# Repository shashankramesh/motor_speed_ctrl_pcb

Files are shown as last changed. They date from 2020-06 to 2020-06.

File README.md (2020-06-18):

# motor_speed_ctrl_pcb

The repository contains the schematic, PCB layout, arduino code and simulation of the motor speed controller.

The speed controller uses ATmega328P-PU SMD microcontroller and includes I2C/SPI/USART communication.
The PCB is also designed to be interfaced with incremental, absolute or potentiometer speed sensors. 
Two or more speed controllers can be daisy chained with I2C communication.

The arduino code uses the PID algorithm for controlling the speed of the motors.

The simulation uses continous and discrete models of the motor whose speed had to be controlled, for tuning the parameters of PID. 
This motor model can be replaced with the model of the motor that has to be controlled.

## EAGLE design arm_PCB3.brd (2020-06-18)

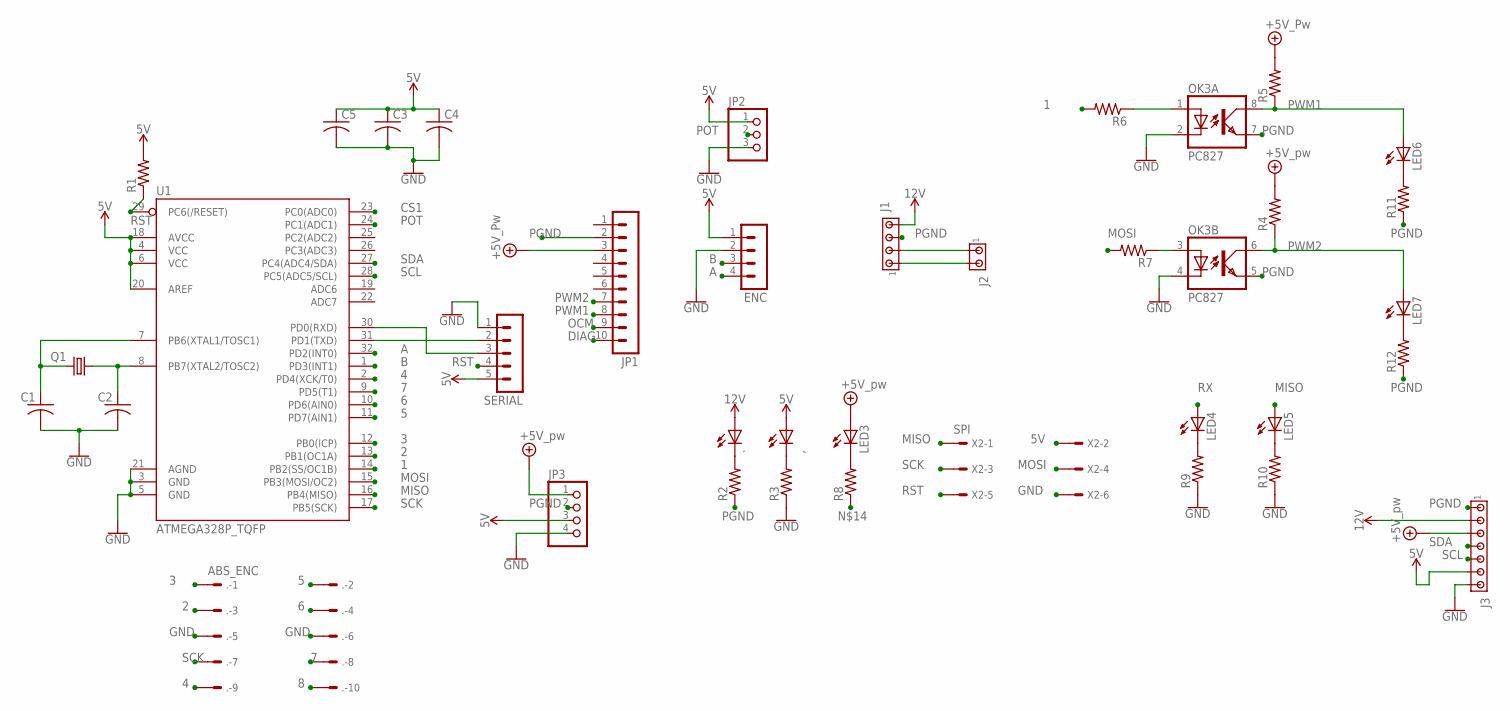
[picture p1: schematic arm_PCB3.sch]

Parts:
,: LEDSMT1206; 1206
.: ABS_ENC; 057-010-1
C1, C2: C-US025-024X044; C025-024X044
C3, C4, C5: C-USC1206; C1206
ENC: MA04-1
J1: MTA04-100; 10X04MTA
J2: MTA02-156; 1X2MTA
J3: MTA07-156; 1X7MTA
JP1: MA10-1
JP2: PINHD-1X3; 1X03
JP3: PINHD-1X4; 1X04
LED3, LED4, LED5, LED6, LED7: LEDSMT1206; 1206
OK3: PC827; DIL08
Q1: CRYSTALHC49U-V; HC49U-V
R1, R2, R3, R4, R5, R6, R7, R8, R9, R10, R11, R12: R-US_R0805; R0805
SERIAL: MA05-1
U1: ATMEGA328P_TQFP; TQFP32-08
X2: SPI; 057-006-1
`: LEDSMT1206; 1206

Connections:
1: R6.2, U1.14 (PB2(SS/OC1B))
2: ..3, U1.13 (PB1(OC1A))
3: ..1, U1.12 (PB0(ICP))
4: ..9, U1.2 (PD4(XCK/T0))
5: ..2, U1.11 (PD7(AIN1))
5V: ,.A, C3.1, C4.1, C5.1, ENC.1, J3.6, JP2.1, JP3.3, R1.2, SERIAL.5, U1.4 (VCC), U1.6 (VCC), U1.18 (AVCC), U1.20 (AREF), X2.2
6: ..4, U1.10 (PD6(AIN0))
7: ..8, U1.9 (PD5(T1))
8: ..10
12V: J1.4, J3.2, `.A
+5V: J3.3, JP1.3, JP3.1, LED3.A, R4.2, R5.2
A: ENC.4, U1.32 (PD2(INT0))
B: ENC.3, U1.1 (PD3(INT1))
CS1: U1.23 (PC0(ADC0))
DIAG: JP1.10
GND: ..5, ..6, C1.2, C2.2, C3.2, C4.2, C5.2, ENC.2, J3.7, JP2.3, JP3.4, OK3.2 (C), OK3.4 (C), R3.1, R9.1, R10.1, SERIAL.1, U1.3 (GND), U1.5 (GND), U1.21 (AGND), X2.6
MISO: LED5.A, U1.16 (PB4(MISO)), X2.1
MOSI: R7.2, U1.15 (PB3(MOSI/OC2)), X2.4
unnamed: C1.1, Q1.2, U1.7 (PB6(XTAL1/TOSC1))
unnamed: J1.2, J2.1
unnamed: C2.1, Q1.1, U1.8 (PB7(XTAL2/TOSC2))
unnamed: R2.2, `.C
unnamed: ,.C, R3.2
unnamed: J1.1, J2.2
unnamed: LED6.C, R11.2
unnamed: LED3.C, R8.2
unnamed: OK3.1 (A), R6.1
unnamed: OK3.3 (A), R7.1
unnamed: LED4.C, R9.2
unnamed: LED5.C, R10.2
unnamed: LED7.C, R12.2
OCM: JP1.9
PGND: J1.3, J3.1, JP1.2, JP3.2, OK3.5 (EMIT), OK3.7 (EMIT), R2.1, R11.1, R12.1
POT: JP2.2, U1.24 (PC1(ADC1))
PWM1: JP1.8, LED6.A, OK3.8 (COL), R5.1
PWM2: JP1.7, LED7.A, OK3.6 (COL), R4.1
RST: R1.1, SERIAL.4, U1.29 (PC6(/RESET)), X2.5
RX: LED4.A, SERIAL.3, U1.30 (PD0(RXD))
SCK: ..7, U1.17 (PB5(SCK)), X2.3
SCL: J3.5, U1.28 (PC5(ADC5/SCL))
SDA: J3.4, U1.27 (PC4(ADC4/SDA))
TX: SERIAL.2, U1.31 (PD1(TXD))

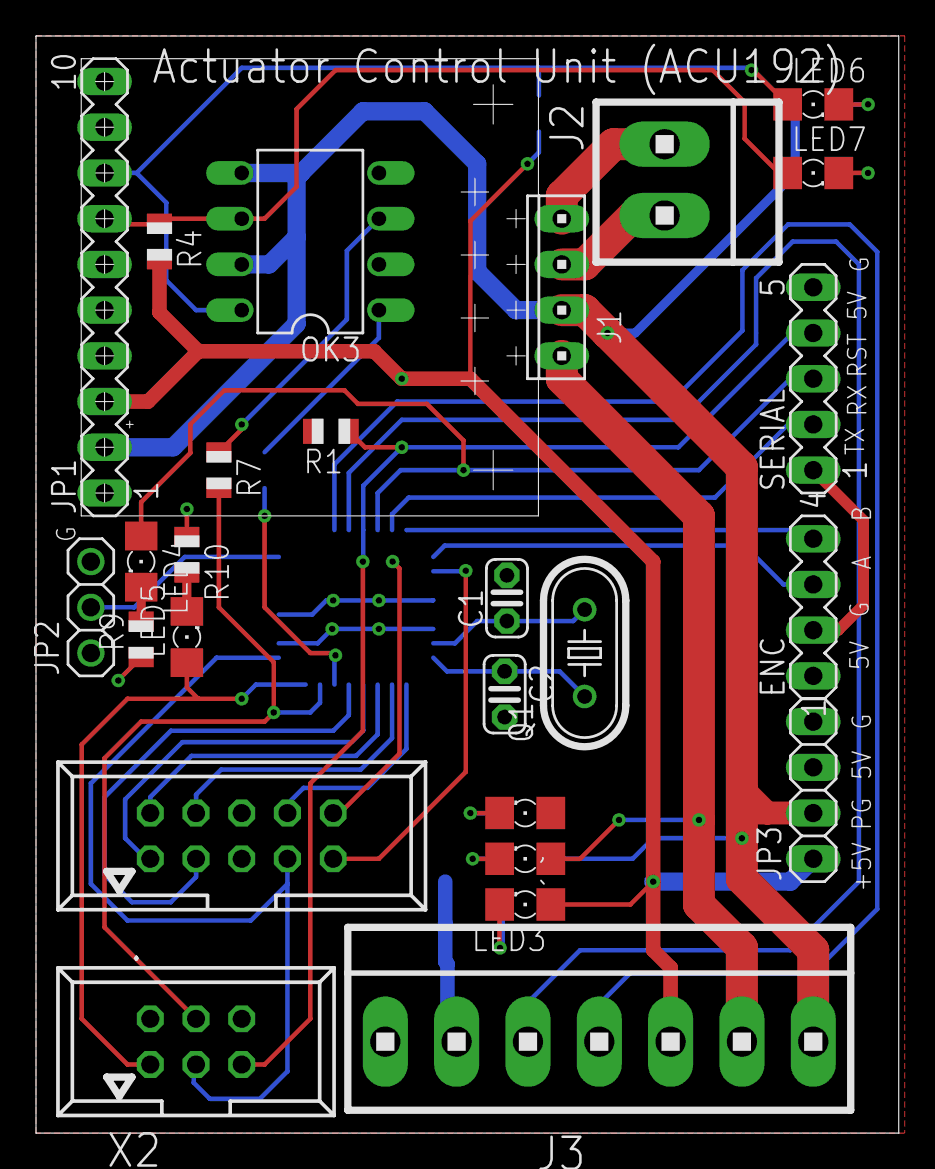
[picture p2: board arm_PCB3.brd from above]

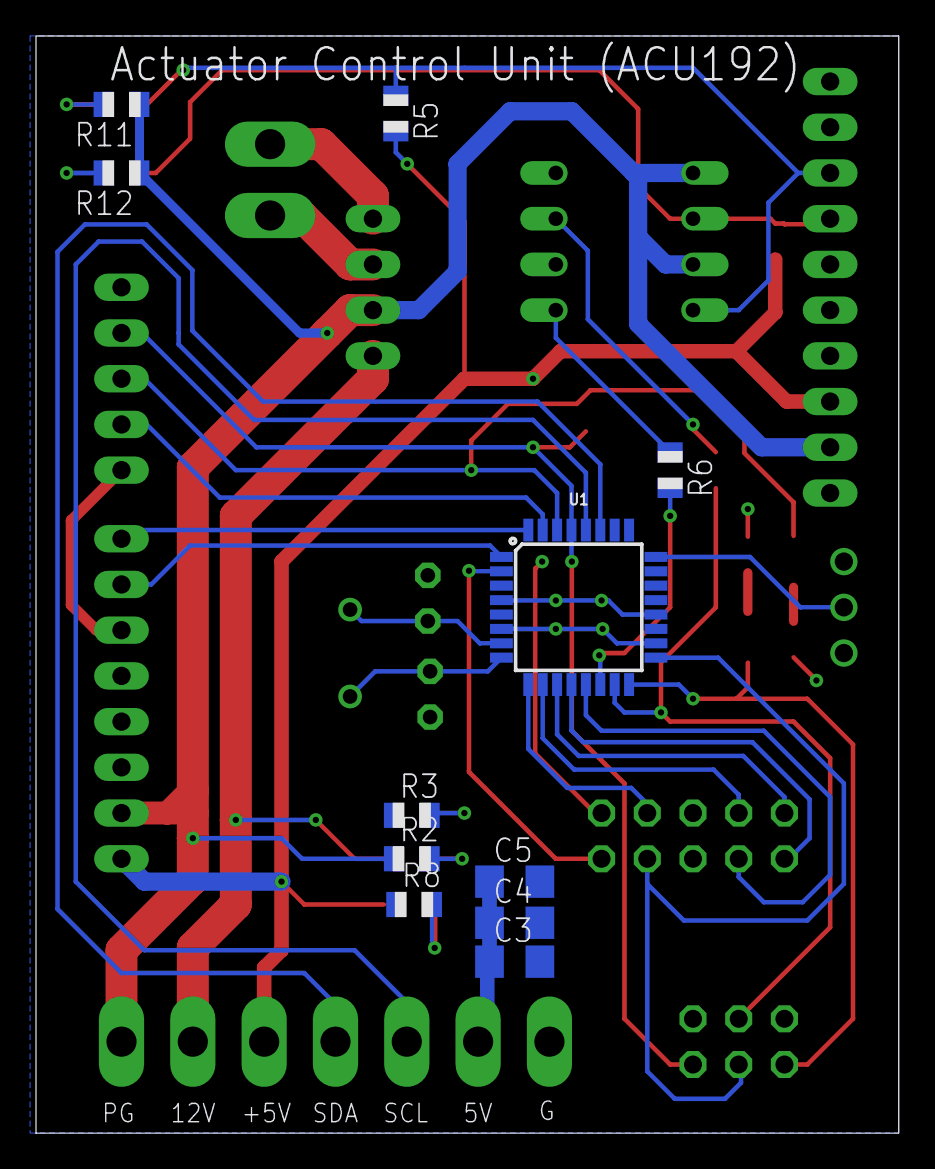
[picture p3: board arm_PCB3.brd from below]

Board: 2 copper layers, 47.9 x 61.0 mm, 37 parts (11 on the bottom side), 38 nets.

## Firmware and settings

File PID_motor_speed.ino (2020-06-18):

#define PWM 11
#define DIR 13
#define SLP 12 
#define sample_length 9
#define n_max 10000
#define enc_constant 0.03481 
#define Kp -13.41
#define Ki -282.434
#define Kd 0.0
#define w_max 15.0

//#include<Wire.h>

int nA = 1;
int nAi = 0;
boolean step_change_A = false;
unsigned long ti = 0;
float wd = 0;
int dt = 0;
int dir = 0;
int sign = 0;
float a = 0, b = 0, c = 0, ek = 0, ek_1 = 0, ek_2 = 0, pwm = 0;


void increment_A(){
  if(digitalRead(3) == HIGH)
  {
    sign = 1;
  }
  else
  {
    sign = -1;
  }
  nA++;
  if(nA > n_max)
  {
    nA = 1;
    step_change_A = true;
  }
}

void setup() {
  pinMode(PWM, OUTPUT);
  pinMode(DIR, OUTPUT);
  pinMode(SLP, OUTPUT);
  pinMode(3, INPUT);

  digitalWrite(SLP, HIGH);

  attachInterrupt(0, increment_A, RISING);

  //Wire.begin();

  ti = micros();

  Serial.begin(115200);
  Serial.println("Enter wd");
  while(Serial.available() == 0);
  wd = Serial.parseInt();

  nAi = nA;
}

void loop() {
  if(abs(wd) < w_max)
  {
    //Change in time
    dt = micros() - ti;
    ti = micros();
  
    //Speed calculations
    int dn = nA - nAi + ((int)step_change_A*n_max);
    nAi = nA;
    if(step_change_A)
    {
      step_change_A = false;
    }
    float w = (float)sign*(float)enc_constant*(float)dn*1000000.0/(float)dt;
  
    //PID
    ek_2 = ek_1;
    ek_1 = ek;
    ek = wd - w;
    a = Kp + (Ki*(float)dt*0.000001/2.0) + (Kd*1000000.0/(float)dt);
    b = -Kp + (Ki*(float)dt*0.000001/2.0) -(2*Kd*1000000.0/(float)dt);
    c = Kd*1000000.0/(float)dt;
    
    pwm = pwm + a*ek + b*ek_1 + c*ek_2;
    
    int pwmi = pwm;
    if( pwmi < 0 )
    {
      digitalWrite(DIR, HIGH);
      pwmi = -pwmi;
    }
    else
    {
      digitalWrite(DIR, LOW);
    }
    constrain(pwmi, 0, 255);
  
    analogWrite(PWM, pwmi);
    Serial.print(w);
    Serial.print("  .......  ");
    Serial.println(dt);
    delay(20);
  }
  else
  {
    Serial.println("Saturation");
  }
}

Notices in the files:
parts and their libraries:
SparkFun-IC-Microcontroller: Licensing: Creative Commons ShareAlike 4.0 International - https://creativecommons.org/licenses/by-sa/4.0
